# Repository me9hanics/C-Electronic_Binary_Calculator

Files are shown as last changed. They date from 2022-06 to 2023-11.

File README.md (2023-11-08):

# Electronic_Binary_Calculator
Calculator using infrared sensors as buttons, currently used as a binary calculator, using an STM32 Nucleo64 microcontroller.
Designed a PCB in Altium Designer and Altium CircuitMaker to the microcontroller. It contains a 16x2 LCD and 16 infrared sensors (and a supply circuit, with  reverse current protection). The infrared sensors are used as buttons, as an object gets close to them, their  output voltage changes, making them applicable as buttons. All 16 sensors are connected to 8 analog inputs of the Nucleo board in pairs, their  values are read simultaneously, one per pair at a time (pairs are multiplexed with transistors). 

The board and the LCD:



The schematic:

Kép1

I also designed a  firmware in C, using the Eclipse-based STM32CubeIDE.

To use all 16 buttons, I have to desolder two solder bridges on the microcontroller. Instead, I only use 8 buttons, and made a binary calculator: it uses only 0 and 1, but displays the value in base 10.

The firmware, using the analog inputs of the microcontroller, detects which sensors are pressed, and based on a state machine I modelled, decides what to write on the LCD and sends this data via UART to the C# client app (see below). The state machine:

diag

The LCD's anode pin isn't working correctly, I probably broke the LCD when putting it wrongly into the board one time. So I made a client application to aid that problem, displaying the calculator's display (and it's buttons). The client app:

kep2

This way I could take the LCD off the board. (The two cables were soldered there to see if it would work this way, but it did not fix it, those cables were desoldered later)

bo

Initially, the project started off as a decimal calculator. However, two solder bridges were needed to be soldered differently than default, causing every sensor "on the sides" not be able to function due to disconnected pins. I figured this out by that time we were only allowed to work on the software, not the hardware anymore, thus I couldn't change it, I had to use only the 8 "inbetween" sensors, creating a binary calculator: works great, but is not very nice. (The client app showcased the numbers and results in decimal, just the input was 1's and 0's, converted immediately).

## About the firmware
Can be found under /Firmware_C/Core/Src/.

## About the hardware
The Altium designs of the PCB can be found in the respective subfolder.

The board gets 5 Volts of power supply, but most pins and the sensors use 3.3V, so I used a Buck converter to get stable 3.3V.
I used CNY70 diodes for infrared light detection. For less power usage, I designed the diodes to drain current when they are touched, not in passive (untouched) state. From the below diagram (upper one), I've found that with 1.1V input voltage results in 10mA forward current, to assert to this, I put a serial resistor in there with 220Ohm resistance (required resistance had to be calculated: 3.3V-1.1V voltage needs to drop on it, and the current equals 10mA, hence R = 2.2V/10mA = 220Ohm). The sensor has a phototransistor, based on the lower diagram, I put a 22kOhm resistor in series with it.



## About the client app
UART communication with the microcontroller.

Files can be found under /ClientApp_CSharp/calc/ , if using Visual Studio, the solution file (calc.sln) can be ran to load the project, else all files are found under /ClientApp_CSharp/calc/calc/.

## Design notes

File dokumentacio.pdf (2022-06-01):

# Mikrokontroller laboratórium házi feladat

## Hanics Mihály Péter

### Neptun-kód: UJ47SY

konzulens: Kovács Adorján

A kitűzött feladat: Számológép készítése érintésérzékeny gombokkal

Készítendő kiegészítő hardver egység az STM32 NUCLEO-F446RE kithez, amely egy 6 digites, a négy alapművelet végrehajtására képes számológépet valósít meg. A számológép egy 2x16 karakteres alfanumerikus kijelzőt és 16 „érintés érzékeny gombot” tartalmazzon, 4x4-es mátrixban elhelyezve. Ezek infravörös szenzorok, melyek az analóg bemenethez illesztendőek. A kijelző fényereje változtatható legyen egy billentyűkombinációval. Műveletet az LCD felső során jelzünk ki, eredményt az alsó felén, képes legyen tizedestörteket kezelni. Eredményt a tizedespont hosszas lenyomása után tudunk törölni.

A házi Altium Designerben megvalósított része:
-1db schematic kapcsolási rajz, amely tartalmazza a Nucleo-t, 16 szenzort, egy LCD-t (melynek schematicját is elkészítettem), kiegészítő áramköri elemeket és egy tápáramkört (az LM 2576S-3.3V elem köré építve adatlapja alapján)
-Footprintet készítettem: LCD-nek a ChipCAD-en talált kép alapján, 100uF-os és 1000uF-os elko-knak adatlapjaikban található méreteik alapján az Altium IPC Wizard segítségével, ugyanezzel egy 100uHy-s induktivitás és a szupresszor dióda footprintjét is elkészítettem. Felhasználtam a tanszéki könyvtárból a CNY70 footprintjét, megfelelő értékű ellenállásokat kerestem melyek méretei (0805) egyeznek a tanszéki ellenállás footprint méretével, szintén felhasználtam a tanszéki táp footprintet és a multifuse footprintet is, melyhez kerestem példányt Lomexen, amit találtam túl nagy áramot bír elviselni. A szupresszor dióda feszültségszintje is 8V ami enyhén magas. Felhasználtam a tanszéki NMOS footprintet, ehhez találtam példányt Lomexen, de az LM2576S-3.3V áramköri elemnek footprintjét a gyártói könyvtárból szereztem.
-PCB Layout, kimeneti fájlok generálása
Kapcsolási rajz:

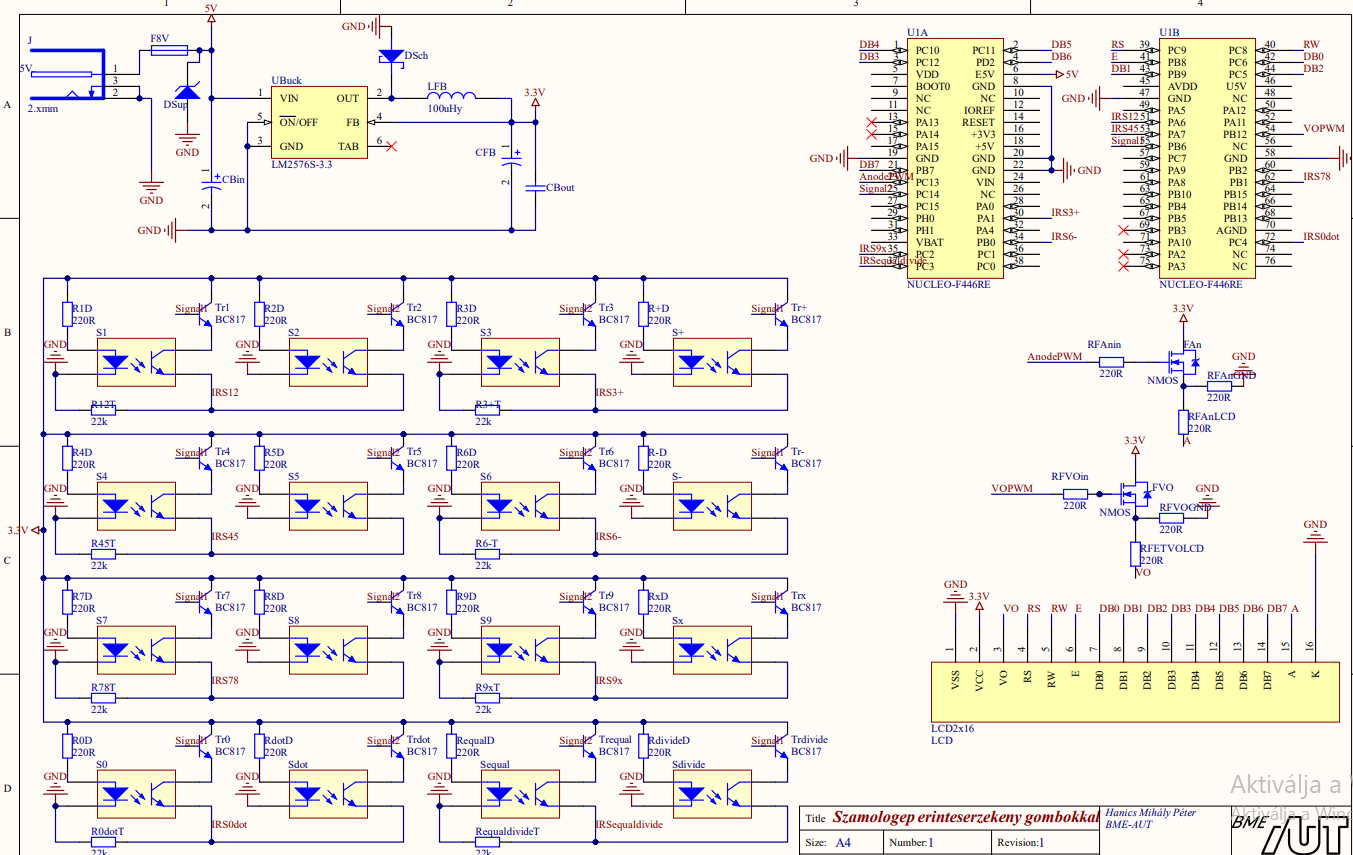
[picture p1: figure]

A Nucleo külső 5V-os tápról van ellátva, a tápáramkör a bal felső sarokban található (LM2576S-3.3V Buck-konvertert használva). A Nucleonak 8db analóg bemenetére csatlakozik 16db infravörös szenzor kimenete (fototranzisztor emittere) és a hozzájuk tartozó áramköri elemek, párokban. A Nucleo PB6 (Signal1) és PC14 (Signal2) lába vezérli azon BJT-ket, melyekkel kiválasztható hogy mely szenzor analóg kimenete jelenjen meg a Nucleo egyes bemenetén. A Nucleonak ezentúl 13 kimenete van csatlakoztatva az LCD-hez, ebből két darab PWM-mel megvalósított, a világításhoz, ehhez tartoznak FETek.

A CNY70 infravörös szenzor működése a következő: egy infravörös emitterdióda adja az infravörös fényt, mely jó fényviszonyban visszatükröződik a fototranzisztor bázisa felé, sötétségben pedig nem tükröződik vissza, a tranzisztor pedig ez alapján nyit vagy zár. Az áramköri kialakítás úgy lett megoldva, hogy ha egy érzékelőhez hozzáérünk, ami nyilvánvalóan a ritkább eset, akkor nyisson a tranzisztor s az analóg bemeneten a feszültség magas (kevesebb fogyasztás). Az ellenállásokat ezen diagram alapján terveztem: Egy leolvasható érték az IF = 10mA, VF = 1.1V. Ez alapján terveztem sorosan ellenállást: a kettőn 3.3V kell essen, áram 10mA, R =

3.3V−VF
IF

, ez alapján R=220Ohm.

A tranzisztor kollektorának potenciálja 3.3V,

szeretnénk nyitáskor minél magasabb feszültséget az emitteren mérni, ezért minimalizálnánk a kollektor-emitter feszültséget, amit az ábra alapján a kollektoráram minimalizálásával tudunk, ezért a kimenettel sorosan kötöttem egy 22kOhmos ellenállást, így minimalizálva az áramot. Az ábra alapján az áram

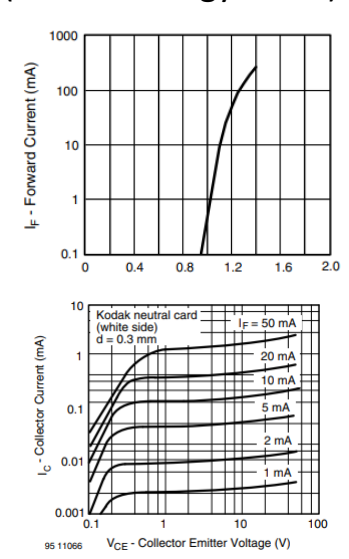
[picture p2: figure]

kb. 0.11mA lehet, így az emitterfeszültség 2.42V (ha az ellenállás pontos, ami nagy ellenállásoknál nem jellemző), VCE pedig kb. 0.9V. A gyakorlatban az ellenállás értéke több, mint 22kOhm, és az emitterfeszültség 2.63V értéket vesz fel tipikusan, ha odaérintjük az ujjunk/egy tollat stb.
A tápáramkör a Buck-konverter adatlapja alapján készült el, ahol pontosan le volt írva, hogy ilyen áramkört kell a Buckhoz illeszteni, specifikált kapacitás és induktivitás értékekkel. A Buck kimenete táplálja az LCD-t és a szenzorokat. Az LCD lábaira digitális értékeket kell adni, időzítve (Enable lábbal).
A feladatmegoldásban az LCD nem vett fel elegendő feszültséget az anód lábán (hiába korrigáltam lebegő vezetékekkel, csak a háttérvilágítás feszültségszintjét sikerült ezzel 3.3V-ra hozni), és többszörösen hibásan működött, így ezt kivettem az áramkörből az utolsó héten és a kliensalkalmazásban szimulálom.

Azon szenzorok, melyekhez tartozó BJT-ket a Signal1 jellel vezéreljük megfelelően működnek (két szélső oszlop), a Signal2 jellel vezéreltek viszont sosem kapnak magas feszültséget, s így páronként csak 1 szenzor volt használható (a „szélsőbbik”). Határidő után derült ki ennek az oka: már a Nucleo PC14 lábán (mely a Signal2 ) sem jelent meg magas feszültség, hiába állítottuk be szoftveresen: a PC14 láb hardveresen oszcillátorhoz tartozó láb, nem GPIO, átállításához 2db solder bridge-t kellett volna változtatni a boardon.

PC kliensalkalmazás:

Az imént említett probléma okán konzulenssel egyeztetve a számológép csak 8 gombját használtam, és bináris számológépet valósítottam meg (gombok: 0 1 . = + - * / ). Az LCD-t a kliensalkalmazásban szimulálhattam.

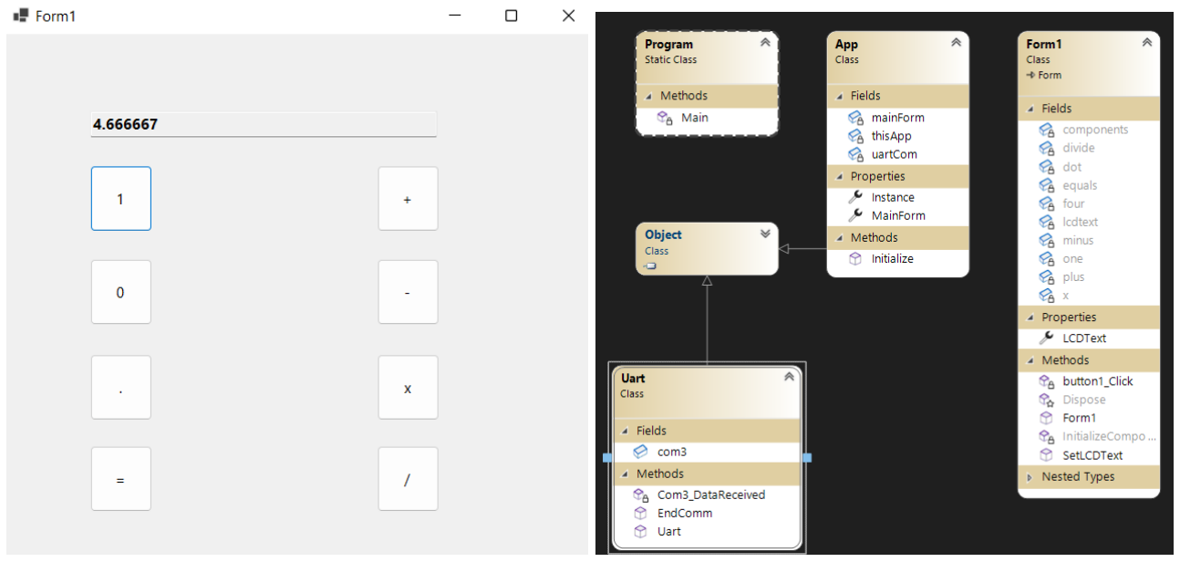
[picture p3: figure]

Firmware blokkvázlat:
A firmware állapotgépszerűen lett megtervezve, az állapotok: firstNumber, clearORsetBrightness, secondNumber, overError, resultOnDisplay. Az állapotok közötti lépkedést egy storedValuesType storedValues; változóval oldjuk meg, ahol a típus tartalmaz egy char-t ami meghatározza hogy mely állapotba lépjünk (például az ’s’ az állapotban maradást jelenti, a ’+’ karakter adódik át ha az első szám után a +-hoz tartozó infravörös szenzort érintjük meg, ekkor pl. firstNumberből secondNumberbe jutunk) és tartalmaz két számot műveletekhez. A blokkvázlata az állapotoknak:

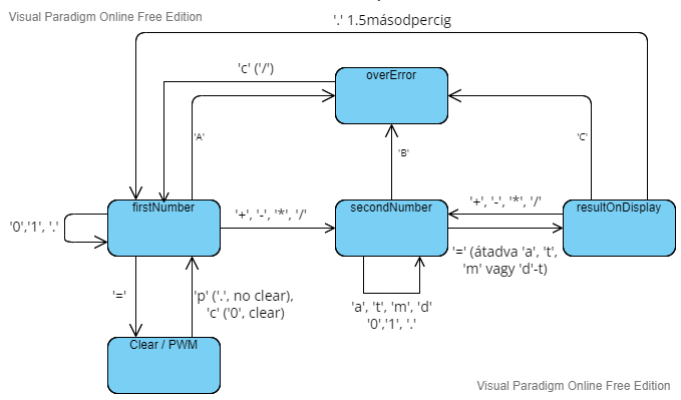
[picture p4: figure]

Belépési pont: firstNumber

Az állapotgép magyarázata: A műveletekben szereplő első operandus a firstNumber állapotban írható, 0, 1 számjegyekkel (és tizedesponttal). Ez tárolódik a storedValues.firstStoredNumber változóban. Miután ezt beírtuk, ha elrontottunk valamit, akkor Clear-elhetünk egyenlőségjelet nyomva, itt visszakérdez a program, hogy biztos akarunk-e clear-elni? Pontot nyomva nem törlődik a szám, 0-t nyomva igen. Beírva a megfelelő számot, lenyomva egy operátort (+, -, *, /) áttérhetünk a második számra, ekkor a storedChar értéke az operátorhoz tartozó karakter lesz, hogy feljegyezzük, hogy mely műveletet hajtsuk majd végre az eredménynél. Itt hasonlóan meg adhatjuk a második szám értékét. Entert nyomva kiíratjuk az eredményt, itt 1.5 másodpercig lenyomva tartva a pontot visszaléphetünk egy új művelet elvégzéséhez. Bármikor meghaladjuk a 16 jegyet egy számban, a program jelzi ezt, s visszaléphetünk clearelve.

Firmware kapcsolata a PC-vel: UART-tal kommunikálnak, méghozzá stringeket átadva. Az adó a Nucleo, a vevő a kliensalkalmazás, a Nucleo mindig olyan stringeket küld, melyek lezáró nullája előtt \n-t tartalmaznak, és így a kliensalkalmazás ReadLine-nal egyszerűen tudja olvasni.
HAL_StatusTypeDef UART_Init(){
MX_USART2_UART_Init();

HAL_UART_Receive_IT(&huart2, (uint8_t*) &rxBuffer, 1 );

}
HAL_StatusTypeDef UART_SendString(char *str){ while(huart2.gState!= HAL_UART_STATE_READY && huart2.gState!= HAL_UART_STATE_BUSY_RX );

strncpy(txBuffer,str,TXBUFFERSIZE); HAL_UART_Transmit_IT(&huart2,(uint8_t* )txBuffer,strlen(txBuffer));

A kliensalkalmazás UART kommunikációja egy külön Uart.cs fájlban van megírva. Itt megadtuk a portot, megírtuk a függvényt, mely adatfogadáskor az adatot kezeli, és a függvényt ami a kommunikációt befejezi lezáráskor.

Működés közben készített kép:

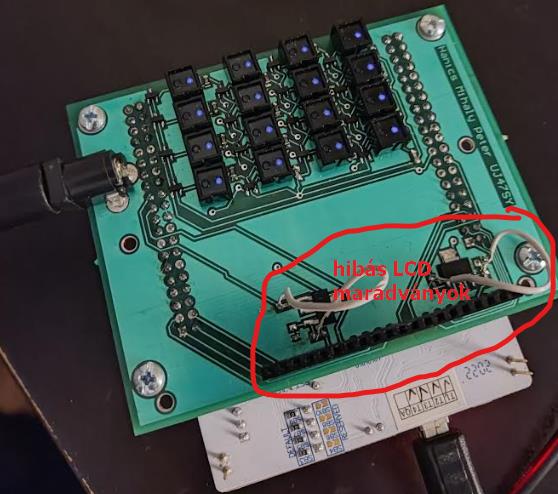
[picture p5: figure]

Utóbbi megjegyzések:

Ha most kezdeném el a házifeladatot, először megnézném, hogy az egyes lábak mire használhatóak, és a gyári beállítások (solder bridge-k, stb.) szerint mire használatosak ezen lábak.

Tudomásul venném, hogy idén a tanszék lényegesen több embert vett fel specializációra, mint más tanévekben, ezért egy konzulens ill. oktató sem tud annyi időt fektetni egy-egy házi feladatba, mint előző években, s többet kell hagyatkozzak magamra és társaimra.

Több önálló döntést hoztam volna.

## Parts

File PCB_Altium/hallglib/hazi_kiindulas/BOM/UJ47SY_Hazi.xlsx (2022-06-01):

Description | Designator | Quantity | Reference | Supplier | ProjectName | Name
Reflective Optical Sensor | S0, S1, S2, S3, S4, S5, S6, S7, S8, S9, S-, S+, Sdivide, Sdot, Sequal, Sx | 16 |  |  | UJ47SY_Hazi.PrjPcb
16x2 LCD | LCD2x16 | 1 | BUY030 | ChipCAD | UJ47SY_Hazi.PrjPcb | ERM1602SBS-6 _ 3.3V
2.xmm DC HEBA25 TÁPFESZÜLTSÉG ALJZAT ZÁRT, NYÁKBA 90° | J | 1 | 43-07-67 | Lomex | UJ47SY_Hazi.PrjPcb | TÁP DC ANYA 5.5/2.1/9.5mm DCS-5521-5
100uF Capacitor | CBin | 1 | 91-00-20 | Lomex | UJ47SY_Hazi.PrjPcb | Electrolytic capacitor
100uH Inductor | LFB | 1 | 93-02-83 | Lomex | UJ47SY_Hazi.PrjPcb | Power Inductor
1000uF Capacitor | CFB | 1 | 91-01-03 | Lomex | UJ47SY_Hazi.PrjPcb | Electrolytic Capacitor
Capacitor | CBout | 1 | 82-13-46 | Lomex | UJ47SY_Hazi.PrjPcb | Capacitor 100nF
Fuse | F8V | 1 | 44-04-73 | Lomex | UJ47SY_Hazi.PrjPcb | Polyfuse 8V 2.6A SMD 1812
NPN General-purpose Transistor | Tr0, Tr1, Tr2, Tr3, Tr4, Tr5, Tr6, Tr7, Tr8, Tr9, Tr-, Tr+, Trdivide, Trdot, Trequal, Trx | 16 | 86-01-94 | Lomex | UJ47SY_Hazi.PrjPcb | BJT
NXP - BSP030,115 - MOSFET, N CH, 30V, 10A, SOT223 | FAn, FVO | 2 | 86-01-40 | Lomex | UJ47SY_Hazi.PrjPcb | BSP89 NMOS 240V 0.35A Small Signal FET
Resistor | R0D, R1D, R2D, R3D, R4D, R5D, R6D, R7D, R8D, R9D, R+D, R-D, RdivideD, RdotD, RequalD, RFAnGND, RFAnin, RFAnLCD, RFETVOLCD, RFVOGND, RFVOin, RxD | 22 | 80-10-78 | Lomex | UJ47SY_Hazi.PrjPcb | CR-05FL7--220R
Resistor | R0dotT, R3+T, R6-T, R9xT, R12T, R45T, R78T, RequaldivideT | 8 | 80-11-02 | Lomex | UJ47SY_Hazi.PrjPcb | CR-05FL7---22k
Schottky diode | DSch | 1 | 83-01-41 | Lomex | UJ47SY_Hazi.PrjPcb | Catch Diode (Schottky)
SIMPLE SWITCHER® 3A Step-Down Voltage Regulator, 5-pin TO-263 | UBuck | 1 | 89-21-81 | Lomex | UJ47SY_Hazi.PrjPcb | Step down regulator
Suppressor Diode | DSup | 1 | 96-00-75 | Lomex | UJ47SY_Hazi.PrjPcb | SMAJ5A
 | U1 | 1 | NUCLEO | Tanszék | UJ47SY_Hazi.PrjPcb | Nucleo F446RE

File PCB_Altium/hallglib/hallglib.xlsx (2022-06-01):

Item # | Column=Supplier | Column=Reference | Column=Name | Column=Quantity
1
2
3

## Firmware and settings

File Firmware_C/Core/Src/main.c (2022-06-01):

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
/* Includes ------------------------------------------------------------------*/
#include "main.h"

/* USER CODE BEGIN Includes */
#include <stdlib.h> //vagy stdio.h kell?
#include <string.h>
#include <math.h>
#include "sensors.h"
#include "digoutputs.h"
#include "lcd2x16.h"
/* USER CODE END Includes */

/* USER CODE BEGIN PTD */

enum States{
	firstNumber,
	clearORsetBrightness,
	secondNumber,
	overError,
	resultOnDisplay
};


/* USER CODE END PTD */

 ADC_HandleTypeDef hadc1;

UART_HandleTypeDef huart2;

/* USER CODE BEGIN PV */


ADC_ChannelConfTypeDef ADC_Channels; //ADC-hez kell

AnalogValuesType analogValues; //Ebben taroljuk analog ertekeket
storedValuesType storedValues;
enum States mainstate = firstNumber;
int cntrPWM=0;
double PWMLVL=0.875; //lehet inkabb int
double result;

// Egyetlen bájtos adatfogadási buffer
char rxBuffer;
// Ide másoljuk a küldés alatt álló stringet. Az UART_SendString() használja.
#define TXBUFFERSIZE 255
char txBuffer[TXBUFFERSIZE];
uint8_t lastReceivedUartCommand = 0;

//Signal1: PB6, Signal2: PC14




/* USER CODE END PV */

void SystemClock_Config(void);
static void MX_GPIO_Init(void);
static void MX_USART2_UART_Init(void);
static void MX_ADC1_Init(void);
/* USER CODE BEGIN PFP */

HAL_StatusTypeDef UART_Init();
HAL_StatusTypeDef UART_SendString(char *str);
void HAL_UART_RxCpltCallback(UART_HandleTypeDef *handle);

void UARTSettings(char* str);
static void LCD2x16_Init(void);
static void TimerandPWM_Init(void);


void GetAnalogValues(void); //ezutan hivjuk meg ketszer, kulonbozo signallal a setHalfOfArrayValues-t
void ADConversion(void);

void calcPWM(void);
void DelayWithPWM(int delay);
double power(double num, int pow);
double shortendoubleto16digits(double r);
void setLCDstringbydouble(double r);

//State Functions
void FirstNumberStateFunction(void);

//outputLCDType CommandTypeToOutputLCDType(commandType command, uint32_t vo_pwm, uint32_t enable, uint32_t a_pwm);
//outputLCDType ClearScreen(void);
	//numberToLCD
void ClearOrSetBrightnessStateFunction(void); //Here we simply set the brightness level, the current PWM values are decided at the end of the loop (pinek: 8 illetve 12)
void SecondNumberStateFunction(void);
void OverErrorStateFunction(void);
void ResultOnDisplayStateFunction(void);



/* USER CODE END PFP */

/* USER CODE BEGIN 0 */

/*      **PUBLIKUS VALTOZOK**       */
outputLCDType outputLCD; //biztos?
commandType command;
char LCDstring[20]; //16db karakter + \n + \0

/* USER CODE END 0 */

/**
  * @brief  The application entry point.
  * @retval int
  */
int main(void)
{
  /* USER CODE BEGIN 1 */


	//char msgUART[17] = {'\0','\0','\0','\0','\0','\0','\0','\0',   '\0','\0','\0','\0','\0','\0','\0','\0'   ,'\0'};; //UARThoz   //FONTOS ATGONNDOLI LEZARO 0-T
	//int darknessLvl = 0;



	storedValues.storedChar='0';
	storedValues.firstStoredNumber=0;
	storedValues.secondStoredNumber=0;
	storedValues.statusDot=0;

	strcpy(LCDstring," ");

	/* USER CODE END 1 */

  /* MCU Configuration--------------------------------------------------------*/

  /* Reset of all peripherals, Initializes the Flash interface and the Systick. */
  HAL_Init();

  /* Configure the system clock */
  SystemClock_Config();

  /* Initialize all configured peripherals */
  MX_GPIO_Init();
  MX_USART2_UART_Init();
  MX_ADC1_Init();
  /* USER CODE BEGIN 2 */
  TimerandPWM_Init();
  LCD2x16_Init();
  UART_Init(); //?

  /* USER CODE END 2 */

  /* Infinite loop */
  /* USER CODE BEGIN WHILE */
  while (1)
  {

	//HAL_GPIO_WritePin(GPIOA, GPIO_PIN_5, GPIO_PIN_SET); //LED

	ADConversion();

	HAL_Delay(1);
	setOutputPin(RS_PIN, 1); //For writing characters
	HAL_Delay(1);


	//WriteLCDChar(1, 0, 'F'); //TESZTKOD
	//HAL_Delay(2000);

	//strcpy(LCDstring,"first test\n"); //EZ MUKODIK!
	//strcat(LCDstring, "+");


	  //lekerdezni bemeneteket + aktualizalas sensors.c valtozojanak, itt kell csak hasznalni a signalt
	 switch(mainstate){
	 	 case firstNumber :
	 		 FirstNumberStateFunction();
	 		 setLCDstringbydoublewithNewline(storedValues.firstStoredNumber);
	 		 break;
	 	 case clearORsetBrightness :
	 		 ClearOrSetBrightnessStateFunction();
	 		 strcpy(LCDstring,"Clear?\n");
	 		 break;
	 	 case secondNumber :
	 		 SecondNumberStateFunction();
	 		 setLCDstringbydoublewithNewline(storedValues.secondStoredNumber);
	 		 break;
	 	 case overError :
	 		 OverErrorStateFunction();
	 		 strcpy(LCDstring,"OverError!\n");
	 		 break;
	 	 case resultOnDisplay:

	 		 ResultOnDisplayStateFunction();
	 		 setLCDstringbydoublewithNewline(shortendoubleto16digits(result));
	 		 break;
	 }

	UART_SendString(LCDstring);

	cntrPWM++;
	if (cntrPWM>31)
		cntrPWM=0;

    /* USER CODE END WHILE */

    /* USER CODE BEGIN 3 */
  } //end of while
  /* USER CODE END 3 */
}

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
/* USER CODE BEGIN 4 */

HAL_StatusTypeDef UART_Init(){
	MX_USART2_UART_Init();

	HAL_UART_Receive_IT(&huart2, (uint8_t*) &rxBuffer, 1 );

}
HAL_StatusTypeDef UART_SendString(char *str){
	while(huart2.gState!= HAL_UART_STATE_READY && huart2.gState!=  HAL_UART_STATE_BUSY_RX );

	strncpy(txBuffer,str,TXBUFFERSIZE);
	HAL_UART_Transmit_IT(&huart2,(uint8_t* )txBuffer,strlen(txBuffer));

}
void HAL_UART_RxCpltCallback(UART_HandleTypeDef *handle){
	if(handle == &huart2){
		lastReceivedUartCommand=(uint8_t) rxBuffer;
		HAL_UART_Receive_IT(handle,(uint8_t*) &rxBuffer,1);

	}
}

void UARTSettings(char* str){
 //
}

void GetAnalogValues(){


	ADC_ChannelConfTypeDef sConfig = {0};


	  /** Configure for the selected ADC regular channel its corresponding rank in the sequencer and its sample time.
	  */
	  sConfig.Channel = ADC_CHANNEL_6;
	  sConfig.Rank = 1;
	  sConfig.SamplingTime = ADC_SAMPLETIME_56CYCLES;
	  if (HAL_ADC_ConfigChannel(&hadc1, &sConfig) != HAL_OK)
	  {
	    Error_Handler();
	  }

	  HAL_ADC_Start(&hadc1);
	  HAL_ADC_PollForConversion(&hadc1, 10);
	  analogValues.irs12 = HAL_ADC_GetValue(&hadc1)*3.3/4096;
	  HAL_ADC_Stop(&hadc1);

	  /** Configure for the selected ADC regular channel its corresponding rank in the sequencer and its sample time.
	  */
	  sConfig.Channel = ADC_CHANNEL_1;
	  //sConfig.Rank = 2;
	  if (HAL_ADC_ConfigChannel(&hadc1, &sConfig) != HAL_OK)
	  {
	    Error_Handler();
	  }

	  HAL_ADC_Start(&hadc1);
	  HAL_ADC_PollForConversion(&hadc1, 10);
	  analogValues.irs3plus = HAL_ADC_GetValue(&hadc1)*3.3/4096;
	  HAL_ADC_Stop(&hadc1);

	  /** Configure for the selected ADC regular channel its corresponding rank in the sequencer and its sample time.
	  */
	  sConfig.Channel = ADC_CHANNEL_7;
	  //sConfig.Rank = 3;
	  if (HAL_ADC_ConfigChannel(&hadc1, &sConfig) != HAL_OK)
	  {
	    Error_Handler();
	  }

	  HAL_ADC_Start(&hadc1);
	  HAL_ADC_PollForConversion(&hadc1, 10);
	  analogValues.irs45 = HAL_ADC_GetValue(&hadc1)*3.3/4096;
	  HAL_ADC_Stop(&hadc1);

	  /** Configure for the selected ADC regular channel its corresponding rank in the sequencer and its sample time.
	  */
	  sConfig.Channel = ADC_CHANNEL_8;
	  //sConfig.Rank = 4;
	  if (HAL_ADC_ConfigChannel(&hadc1, &sConfig) != HAL_OK)
	  {
	    Error_Handler();
	  }

	  HAL_ADC_Start(&hadc1);
	  HAL_ADC_PollForConversion(&hadc1, 10);
	  analogValues.irs6minus = HAL_ADC_GetValue(&hadc1)*3.3/4096;
	  HAL_ADC_Stop(&hadc1);

	  /** Configure for the selected ADC regular channel its corresponding rank in the sequencer and its sample time.
	  */
	  sConfig.Channel = ADC_CHANNEL_9;
	  //sConfig.Rank = 5;
	  if (HAL_ADC_ConfigChannel(&hadc1, &sConfig) != HAL_OK)
	  {
	    Error_Handler();
	  }

	  HAL_ADC_Start(&hadc1);
	  HAL_ADC_PollForConversion(&hadc1, 10);
	  analogValues.irs78 = HAL_ADC_GetValue(&hadc1)*3.3/4096;
	  HAL_ADC_Stop(&hadc1);
	  /** Configure for the selected ADC regular channel its corresponding rank in the sequencer and its sample time.
	  */
	  sConfig.Channel = ADC_CHANNEL_12;
	  //sConfig.Rank = 6;
	  if (HAL_ADC_ConfigChannel(&hadc1, &sConfig) != HAL_OK)
	  {
	    Error_Handler();
	  }

	  HAL_ADC_Start(&hadc1);
	  HAL_ADC_PollForConversion(&hadc1, 10);
	  analogValues.irs9x = HAL_ADC_GetValue(&hadc1)*3.3/4096;
	  HAL_ADC_Stop(&hadc1);

	  /** Configure for the selected ADC regular channel its corresponding rank in the sequencer and its sample time.
	  */
	  sConfig.Channel = ADC_CHANNEL_14;
	  //sConfig.Rank = 7;
	  if (HAL_ADC_ConfigChannel(&hadc1, &sConfig) != HAL_OK)
	  {
	    Error_Handler();
	  }

	  HAL_ADC_Start(&hadc1);
	  HAL_ADC_PollForConversion(&hadc1, 10);
	  analogValues.irs0dot = HAL_ADC_GetValue(&hadc1)*3.3/4096;
	  HAL_ADC_Stop(&hadc1);

	  /** Configure for the selected ADC regular channel its corresponding rank in the sequencer and its sample time.
	  */
	  sConfig.Channel = ADC_CHANNEL_13;
	  //sConfig.Rank = 8;
	  if (HAL_ADC_ConfigChannel(&hadc1, &sConfig) != HAL_OK)
	  {
	    Error_Handler();
	  }

	  HAL_ADC_Start(&hadc1);
	  HAL_ADC_PollForConversion(&hadc1, 10);
	  analogValues.irsequaldivide = HAL_ADC_GetValue(&hadc1)*3.3/4096;
	  HAL_ADC_Stop(&hadc1);


} //End of GetAnalogValues() function


void ADConversion(void){
	HAL_GPIO_WritePin(GPIOC, GPIO_PIN_14, GPIO_PIN_RESET); //Signal2
	HAL_GPIO_WritePin(GPIOB, GPIO_PIN_6, GPIO_PIN_SET); //Signal1
	HAL_Delay(10);

	GetAnalogValues();
	//setHalfOfArrayValues(analogValues, 0);
	setBitCalcArrayValues(analogValues);

	/*HAL_GPIO_WritePin(GPIOB, GPIO_PIN_6, GPIO_PIN_RESET); //Signal1
	HAL_GPIO_WritePin(GPIOC, GPIO_PIN_14, GPIO_PIN_SET); //Signal2   //LAB NEM MEGY 3.3V-BA!!!
	HAL_Delay(10);

	GetAnalogValues();
	setHalfOfArrayValues(analogValues, 1);

	HAL_GPIO_WritePin(GPIOC, GPIO_PIN_14, GPIO_PIN_RESET); //Signal2 */
}


void LCD2x16_Init(void)
{


	setOutputPin(RW_PIN,0);
	setOutputPin(E_PIN, 0);
	setOutputPin(RS_PIN,0);

	setOutputPin(A_PWM_PIN,1);
	setOutputPin(VO_PWM_PIN,1);

	HAL_Delay(60); //From the data sheet, setup time is at least 40ms after VDD reaches 2.7V and further initialization delays occur

	//1st step: Required initialization
	//1st command: 8 bit bus, 1 line display, 5x8   0  0 | 0 0 1 1 0 0 X X (RS RW DB7-DB0)

	WriteLCDBinary(0, 0, 0x30); //1st function set
	HAL_Delay(10);
	WriteLCDBinary(0, 0, 0x30); //2nd function set
	HAL_Delay(1);
	WriteLCDBinary(0, 0, 0x30); //3rd function set
	HAL_Delay(1);
	WriteLCDBinary(0, 0, 0x38);	//8 bit interface, 2 rows, 5x8 character font
	HAL_Delay(1);
	WriteLCDBinary(0, 0, 0x08);	//Display OFF
	HAL_Delay(1);
	WriteLCDBinary(0, 0, 0x01);	//Clear display
	HAL_Delay(1);
	WriteLCDBinary(0, 0, 0x06); //Entry mode: cursor to the right, no shifting
	HAL_Delay(1); //lehet talan tobb varakozas
	//WriteLCDBinary(0, 0, 0x0C); //Display on, no cursor
	WriteLCDBinary(0, 0, 0x0F); //Display on with cursor


} //End of LCDInit() function

static void TimerandPWM_Init(void){
	HAL_GPIO_WritePin(GPIOB, GPIO_PIN_6, GPIO_PIN_SET); //Signal1
	HAL_GPIO_WritePin(GPIOC, GPIO_PIN_14, GPIO_PIN_RESET); //Signal2

	HAL_GPIO_WritePin(GPIOB, GPIO_PIN_12, GPIO_PIN_SET);
	HAL_GPIO_WritePin(GPIOC, GPIO_PIN_13, GPIO_PIN_SET);
} //End of PWMInit() function


void calcPWM(void){
	int x = (int) 32*PWMLVL;
	int y = cntrPWM < x ? 1 : 0;
	setPWMPins(y, y);
}
void DelayWithPWM(int delay){
	int i=0;
	for (i=0; i< delay; i++){
		HAL_Delay(1);
		calcPWM();
		cntrPWM++;
		if (cntrPWM>31)
				cntrPWM=0;
	}
}

double power(double num, int pow){
	int i;
	double out=1;
	for(i=0;i<pow;i++){
		out=out*num;
	}
	return out;
}

double shortendoubleto16digits(double r){
	double x = r;
	double z;
	long long y;
	int k=0;
	int i;
	if(x==0)
		return 0;
	while (x<10000000000000000){
		x=x*10;
		k++;
	}
	x=x/10;  //Assuming given double wasn't bigger than 10^16-1 = 9999...99 (16 darab)
	y = (long long) x;
	x = y;
	z=x;
	//modf(x,&z);
	for(i=0;i<k-1;i++)
		z=z/10;
	return z;
}
void setLCDstringbydoublewithNewline(double r){
	char outer[16];
	snprintf(outer,16,"%f",r);
	strcpy(LCDstring,outer);
	strcat(LCDstring,"\n" );
}
char* doubletostring(double r){
	char copy[20];
	char outer[16];
	snprintf(outer,16,"%f",r);
	strcpy(copy,outer);
	return copy;
}
///////////////////////////////////////////////////////////////////////////////////////////////////////

void FirstNumberStateFunction(void){

	switch(storedValues.storedChar){
		case '0':
			storedValues.firstStoredNumber= storedValues.statusDot<1? 2*storedValues.firstStoredNumber + 0 : storedValues.firstStoredNumber + 0 * power(0.5, storedValues.statusDot);
			if(storedValues.statusDot>0)
				storedValues.statusDot++;

			setLCDstringbydoublewithNewline(storedValues.firstStoredNumber);
			UART_SendString(LCDstring);
			WriteLCDChar(1, 0, '0');
			DelayWithPWM(1500);
			ADConversion();
			storedValues.storedChar='s';
			break;
		case '1':
			storedValues.firstStoredNumber= storedValues.statusDot<1? 2*storedValues.firstStoredNumber + 1 : storedValues.firstStoredNumber + 1 * power(0.5, storedValues.statusDot);
			if(storedValues.statusDot>0)
				storedValues.statusDot++;
			setLCDstringbydoublewithNewline(storedValues.firstStoredNumber);
			UART_SendString(LCDstring);
			WriteLCDChar(1, 0, '1');
			DelayWithPWM(1500);
			ADConversion();
			storedValues.storedChar='s';
			break;

		case 'p':
			ClearScreen();
			ReturnHome();
			storedValues.storedChar='s';
			break;
		case 'c':
			ClearScreen();
			ReturnHome();
			strcpy(LCDstring,"CLEARING\n");
			UART_SendString(LCDstring);
			storedValues.firstStoredNumber=0;
			storedValues.statusDot=0;
			storedValues.secondStoredNumber=0;
			storedValues.storedChar='s';
			DelayWithPWM(800);
			break;
		default: break;


	}  //storedChar kezeles pl. 'n'-re eloszor kis delay

	//megnezni a bemenetek kozul van-e ami le van nyomva
	if(sensorArray.irs0>0)
		storedValues.storedChar='0';
	if(sensorArray.irs1>0)
		storedValues.storedChar='1';


	if(sensorArray.irsdot>0){
		if(storedValues.statusDot==0){
			storedValues.statusDot=1;
			WriteLCDChar(1, 0, '.');
		}

	}

	if(sensorArray.irsequal>0){
		mainstate = clearORsetBrightness;
		storedValues.storedChar='=';
	}


	if(sensorArray.irsplus>0){
		mainstate = secondNumber;
		storedValues.storedChar='+';
		storedValues.statusDot=0;
	}

	if(sensorArray.irsminus>0){
		mainstate = secondNumber;
		storedValues.storedChar='-';
		storedValues.statusDot=0;
	}
	if(sensorArray.irsx>0){
		mainstate = secondNumber;
		storedValues.storedChar='x';
		storedValues.statusDot=0;
	}
	if(sensorArray.irsdivide>0){
		mainstate = secondNumber;
		storedValues.storedChar='/';
		storedValues.statusDot=0;
	}

	if(storedValues.firstStoredNumber*power(10, storedValues.statusDot)>power(10, 16)-1){
		mainstate = overError;
		storedValues.storedChar='A';
	}
}

void ClearOrSetBrightnessStateFunction(void){
	switch(storedValues.storedChar){
		case '=':
			ClearScreen();
			WriteLCDChar(1, 0, 'C');
			WriteLCDChar(1, 0, 'l');
			WriteLCDChar(1, 0, 'e');
			WriteLCDChar(1, 0, 'a');
			WriteLCDChar(1, 0, 'r');
			WriteLCDChar(1, 0, '/');
			WriteLCDChar(1, 0, 'P');
			WriteLCDChar(1, 0, 'W');
			WriteLCDChar(1, 0, 'M');

			//TODO itt UART kuldes?
			DelayWithPWM(800);
			break;
		/*case '+':
			PWMLVL = 1 - (1-PWMLVL)/2 ;
			break;
		case '-':
			PWMLVL = 1 - (1-PWMLVL)*2 ;
			break;*/
		default: break;
	}

	if(sensorArray.irs0>0){
		mainstate = firstNumber;

		storedValues.storedChar='c';
	}
	if(sensorArray.irsdot>0){
		mainstate = firstNumber;
		storedValues.storedChar='p';
	}


}

void SecondNumberStateFunction(void){

	switch(storedValues.storedChar){

		case '+':
			WriteLCDChar(1, 0, '+');
			storedValues.storedChar='a';
			break;
		case '-':
			WriteLCDChar(1, 0, '-');
			storedValues.storedChar='t';
			break;
		case 'x':
			WriteLCDChar(1, 0, '*');
			storedValues.storedChar='m';
			break;
		case '/':
			WriteLCDChar(1, 0, '/');
			storedValues.storedChar='d';
			break;

		default: break; //cases 'a', 't', 'm', 'd'
	}



	if(sensorArray.irsdot>0){
			if(storedValues.statusDot==0){
				storedValues.statusDot=1;
				WriteLCDChar(1, 0, '.');
			}

	}

	if(sensorArray.irsequal>0 ){
		mainstate = resultOnDisplay;
	}



	if(sensorArray.irs0>0){
		storedValues.secondStoredNumber= storedValues.statusDot<1? 2*storedValues.secondStoredNumber + 0 : storedValues.secondStoredNumber + 0 * power(0.5, storedValues.statusDot);
		if(storedValues.statusDot>0)
			storedValues.statusDot++;
		WriteLCDChar(1, 0, '0');
		setLCDstringbydoublewithNewline(storedValues.secondStoredNumber); //TODO felturbozni hogy latszon muvelet
		UART_SendString(LCDstring);
		DelayWithPWM(1500);
	}

	if(sensorArray.irs1>0){
		storedValues.secondStoredNumber= storedValues.statusDot<1? 2*storedValues.secondStoredNumber + 1 : storedValues.secondStoredNumber + 1 * power(0.5, storedValues.statusDot);
		if(storedValues.statusDot>0)
			storedValues.statusDot++;
		WriteLCDChar(1, 0, '1');
		setLCDstringbydoublewithNewline(storedValues.secondStoredNumber);
		UART_SendString(LCDstring);
		DelayWithPWM(1500);
	}

	if(storedValues.secondStoredNumber*power(10, storedValues.statusDot)>power(10, 15)-1){ //TODO felturbozni
			mainstate = overError;
			storedValues.storedChar='B';
	}

}

void ResultOnDisplayStateFunction(void){
	Return2ndRow();
	switch(storedValues.storedChar){
		case 'a':
			if(storedValues.firstStoredNumber+storedValues.secondStoredNumber<power(10, 15)){
				NumberToLCD(storedValues.firstStoredNumber+storedValues.secondStoredNumber);
				result =storedValues.firstStoredNumber+storedValues.secondStoredNumber;
				setLCDstringbydoublewithNewline(result);
				UART_SendString(LCDstring);
				DelayWithPWM(1500);
				ADConversion();
				//esetleg 1st numberbe el is tarolni eredmenyt
				storedValues.storedChar='s';
			}
			else{
				mainstate = overError;
				storedValues.storedChar='C';
			}
			break;
		case 't':
				NumberToLCD(storedValues.firstStoredNumber-storedValues.secondStoredNumber);
				result =storedValues.firstStoredNumber-storedValues.secondStoredNumber;
				setLCDstringbydoublewithNewline(result);
				UART_SendString(LCDstring);

				DelayWithPWM(1500);
				ADConversion();
				storedValues.storedChar='s';
			break;
		case 'm':
			if(storedValues.firstStoredNumber*storedValues.secondStoredNumber<power(10, 15)){
				NumberToLCD(storedValues.firstStoredNumber*storedValues.secondStoredNumber);
				result =storedValues.firstStoredNumber*storedValues.secondStoredNumber;
				setLCDstringbydoublewithNewline(result);
				UART_SendString(LCDstring);

				DelayWithPWM(1500);
				ADConversion();
				storedValues.storedChar='s';
			}
			else{
				mainstate = overError;
				storedValues.storedChar='C';
			}
			break;
		case 'd':
			NumberToLCD(storedValues.firstStoredNumber/storedValues.secondStoredNumber);

			result =shortendoubleto16digits(storedValues.firstStoredNumber/storedValues.secondStoredNumber);
			setLCDstringbydoublewithNewline(result);
			UART_SendString(LCDstring);

			DelayWithPWM(1500);
			storedValues.storedChar='s';
			break;
	}
	if(sensorArray.irsdot>0 && storedValues.storedChar!='C'){
		DelayWithPWM(500);
		if(sensorArray.irsdot>0){
			DelayWithPWM(500);
			if(sensorArray.irsdot>0){
				mainstate=firstNumber;
				storedValues.storedChar='c';
			}
		}

	}
	if(sensorArray.irsplus>0 && storedValues.storedChar!='C'){
		mainstate=secondNumber;
		storedValues.storedChar='+';
		storedValues.statusDot=0;
		storedValues.firstStoredNumber+=storedValues.secondStoredNumber;
		storedValues.secondStoredNumber=0;
	}

	if(sensorArray.irsminus>0 && storedValues.storedChar!='C'){
		mainstate=secondNumber;
		storedValues.storedChar='-';
		storedValues.statusDot=0;
		storedValues.firstStoredNumber-=storedValues.secondStoredNumber;
		storedValues.secondStoredNumber=0;
	}
	if(sensorArray.irsx>0 && storedValues.storedChar!='C'){
		mainstate=secondNumber;
		storedValues.storedChar='x';
		storedValues.statusDot=0;
		storedValues.firstStoredNumber*=storedValues.secondStoredNumber;
		storedValues.secondStoredNumber=0;
	}
	if(sensorArray.irsdivide>0 && storedValues.storedChar!='C'){
		mainstate=secondNumber;
		storedValues.storedChar='/';
		storedValues.statusDot=0;
		storedValues.firstStoredNumber= shortendoubleto16digits(storedValues.firstStoredNumber / storedValues.secondStoredNumber);
		storedValues.secondStoredNumber=0;

	}
}

void OverErrorStateFunction(void){
	switch(storedValues.storedChar){
		case 'A':
			ClearScreen();
			WriteLCDChar(1, 0, 'T');
			WriteLCDChar(1, 0, 'U');
			WriteLCDChar(1, 0, 'L');
			WriteLCDChar(1, 0, ' ');
			WriteLCDChar(1, 0, 'N');
			WriteLCDChar(1, 0, 'A');
			WriteLCDChar(1, 0, 'G');
			WriteLCDChar(1, 0, 'Y');
			storedValues.storedChar='s';
			DelayWithPWM(1500);
			break;
		case 'B':
			ClearScreen();
			WriteLCDChar(1, 0, 'T');
			WriteLCDChar(1, 0, 'U');
			WriteLCDChar(1, 0, 'L');
			WriteLCDChar(1, 0, ' ');
			WriteLCDChar(1, 0, 'N');
			WriteLCDChar(1, 0, 'A');
			WriteLCDChar(1, 0, 'G');
			WriteLCDChar(1, 0, 'Y');
			storedValues.storedChar='s';
			DelayWithPWM(1500);
			break;
		case 'C':
			ClearScreen();
			WriteLCDChar(1, 0, 'T');
			WriteLCDChar(1, 0, 'U');
			WriteLCDChar(1, 0, 'L');
			WriteLCDChar(1, 0, ' ');
			WriteLCDChar(1, 0, 'N');
			WriteLCDChar(1, 0, 'A');
			WriteLCDChar(1, 0, 'G');
			WriteLCDChar(1, 0, 'Y');
			storedValues.storedChar='s';
			DelayWithPWM(1500);
			break;
		default: break;
	}

	if(sensorArray.irsdivide>0){
		mainstate = firstNumber;
		storedValues.storedChar='c';
	}


}


/* USER CODE END 4 */
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


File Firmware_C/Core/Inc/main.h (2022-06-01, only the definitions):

#define ADC_COMPARE_LVL  2.5  // valamiert ha ki van takarva akkor szinte mindig 2.62-2.63 volt egyedul kivetel irs78 ami inkabb 2.5V
#define IRS78_COMPARE_LVL 2.3
#define USART_TX_Pin GPIO_PIN_2
#define USART_TX_GPIO_Port GPIOA
#define USART_RX_Pin GPIO_PIN_3
#define USART_RX_GPIO_Port GPIOA
#define LD2_Pin GPIO_PIN_5
#define LD2_GPIO_Port GPIOA
#define TMS_Pin GPIO_PIN_13
#define TMS_GPIO_Port GPIOA
#define TCK_Pin GPIO_PIN_14
#define TCK_GPIO_Port GPIOA
#define SWO_Pin GPIO_PIN_3
#define SWO_GPIO_Port GPIOB

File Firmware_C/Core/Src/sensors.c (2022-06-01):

/*
 * sensors.c
 *
 *  Created on: 2022. ápr. 17.
 *      Author: hanic
 */

#include "main.h"
#include "sensors.h"

sensorArrayType sensorArray; //extern


void setHalfOfArrayValues(AnalogValuesType values, uint32_t signal){
	if(signal==0){
		sensorArray.irs1=values.irs12 > ADC_COMPARE_LVL ? 1 : 0;
		sensorArray.irsplus=values.irs3plus > ADC_COMPARE_LVL ? 1 : 0;
		sensorArray.irs4=values.irs45 > ADC_COMPARE_LVL ? 1 : 0;
		sensorArray.irsminus=values.irs6minus > ADC_COMPARE_LVL ? 1 : 0;
		sensorArray.irs7=values.irs78 > IRS78_COMPARE_LVL ? 1 : 0;
		sensorArray.irsx=values.irs9x > ADC_COMPARE_LVL ? 1 : 0;
		sensorArray.irs0=values.irs0dot > ADC_COMPARE_LVL ? 1 : 0;
		sensorArray.irsdivide=values.irsequaldivide > ADC_COMPARE_LVL ? 1 : 0;
	}
	else{
		sensorArray.irs2=values.irs12 > ADC_COMPARE_LVL ? 1 : 0;
		sensorArray.irs3=values.irs3plus > ADC_COMPARE_LVL ? 1 : 0;
		sensorArray.irs5=values.irs45 > ADC_COMPARE_LVL ? 1 : 0;
		sensorArray.irs6=values.irs6minus > ADC_COMPARE_LVL ? 1 : 0;
		sensorArray.irs8=values.irs78 > ADC_COMPARE_LVL ? 1 : 0;
		sensorArray.irs9=values.irs9x > ADC_COMPARE_LVL ? 1 : 0;
		sensorArray.irsdot=values.irs0dot > ADC_COMPARE_LVL ? 1 : 0;
		sensorArray.irsequal=values.irsequaldivide > ADC_COMPARE_LVL ? 1 : 0;
	}
}//End of setHalfOfArrayValues() function

void setBitCalcArrayValues(AnalogValuesType values){
		sensorArray.irs1=values.irs12 > ADC_COMPARE_LVL ? 1 : 0;
		sensorArray.irsplus=values.irs3plus > ADC_COMPARE_LVL ? 1 : 0;
		sensorArray.irs0=values.irs45 > ADC_COMPARE_LVL ? 1 : 0;
		sensorArray.irsminus=values.irs6minus > ADC_COMPARE_LVL ? 1 : 0;
		sensorArray.irsdot=values.irs78 > ADC_COMPARE_LVL ? 1 : 0;
		sensorArray.irsx=values.irs9x > ADC_COMPARE_LVL ? 1 : 0;
		sensorArray.irsequal=values.irs0dot > ADC_COMPARE_LVL ? 1 : 0;
		sensorArray.irsdivide=values.irsequaldivide > ADC_COMPARE_LVL ? 1 : 0;


} //End of setBitCalcArrayValues() function

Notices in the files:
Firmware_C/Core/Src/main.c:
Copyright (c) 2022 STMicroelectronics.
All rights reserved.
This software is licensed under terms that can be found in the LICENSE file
